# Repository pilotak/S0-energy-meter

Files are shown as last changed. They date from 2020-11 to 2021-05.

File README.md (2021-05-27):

# S0 energy meter
ESP8266 based pulse counter for home utility meter compatible with ESPHome, Tasmota, etc.

## Basic model
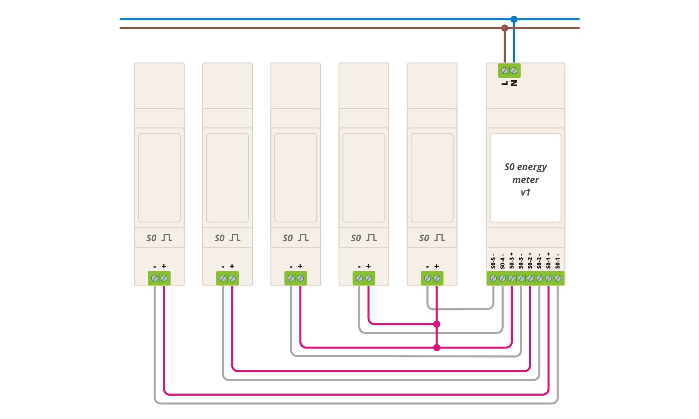
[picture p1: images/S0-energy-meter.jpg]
S0-energy-meter


**Features**:
- 230V direct power supply
- 5x S0 pulse meter input
- [ESPHome config](./config/S0-energy-meter.yaml)

## Enhanced model
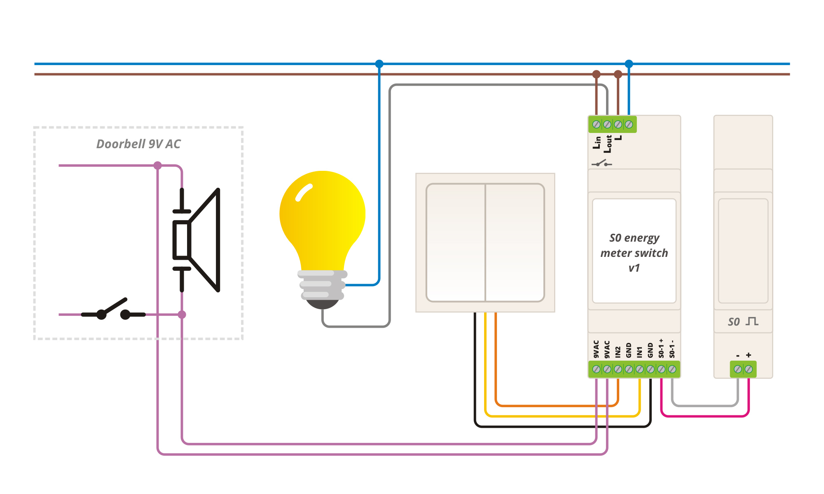
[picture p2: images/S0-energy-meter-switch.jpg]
S0-energy-meter-switch


**Features**:
- 230V direct power supply
- 1x S0 pulse meter input
- 2x input ie. for button or door sensor
- 1x SSR relay for light
- doorbell detection
- [ESPHome config](./config/S0-energy-meter-switch.yaml)

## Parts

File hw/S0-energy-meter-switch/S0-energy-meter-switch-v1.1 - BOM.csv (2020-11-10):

Qty | Value | Package | Description | Part
2 | 22uF/50V | PANASONIC_C | Aluminium Capacitor | C1, C5
1 | 10uF/6.3V | CT3528 | Tantalum Capacitor | C2
3 | 100n | C0805 | Ceramic Capacitor | C3, C4, C7
1 | 100n | C0805 | Ceramic Capacitor | C6
1 | 10uF/6.3V | C0805 | Ceramic Capacitor | C8
6 | KF350-3.5-2P | KF350-3.50-2P | Screw terminal 3.5mm pitch | CON1, CON2, CON3, CON4, CON5, CON6
1 | SS14 | DO214AC | Schottky Barrier Rectifier | D1
2 | UCLAMP3301D.TCT | SOD323 | Low Voltage μClamp TVS diode | D2, D5
1 | 1N4148WS | SOD323 | Fast Switching Diode | D3
1 | BAT54S | SOT23 | Schottky Diodes | D4
1 | TLP184 | SOP04 | AC Photocoupler | IC1
1 | 74LVC1G14GW.125 | SC70-5 | Single Schmitt-Trigger Inverter Gate | IC2
1 | MCP16301T-I/CH | SOT23-6 | High-Voltage Step-Down Regulator | IC3
1 | G3MB-202P-DC24 | G3MB | SSR Relay Zero Cross 2A, 100-240 VAC | K1
1 | DJNR3015-150 | L3015 | SMD Power Coil | L1
1 | RED | LED0805 | SMD LED Diode | LED1
2 | BC817-40SMD | SOT23-BEC | NPN Transistor | Q1, Q2
1 | 3K3 | R1206 | Resistor | R1
2 | 1K | R0805 | Resistor | R2, R13
10 | 10K | R0805 | Resistor | R3, R4, R5, R7, R10, R11, R12, R14, R15, R16
1 | 330R | R0805 | Resistor | R6
1 | 31K6 1% | R0805 | Resistor | R8
1 | 10K 1% | R0805 | Resistor | R9
1 | 820R | R0805 | Resistor | R17
1 | AC-DC_3.6W_24V_150mA | Module | AC-DC regulator | U1
1 | ESP8266-12 | ESP-12 | WIFI Module | U2

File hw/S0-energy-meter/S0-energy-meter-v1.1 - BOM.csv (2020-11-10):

Qty | Value | Package | Description | Part
2 | 22uF/50V | PANASONIC_C | Aluminium Capacitor | C1, C3
2 | 100n | C0805 | Ceramic Capacitor | C2, C5
1 | 100n | C0805 | Ceramic Capacitor | C4
1 | 10uF/6.3V | C0805 | Ceramic Capacitor | C6
4 | KF350-3.5-2P | KF350-3.50-2P | 2P Screw terminal 3.5mm pitch | CON1, CON2, CON3, CON4
1 | KF301-5.08-2P | KF301-5.08-2P | 2P Screw terminal 5.08mm pitch | CON5
1 | SS14 | DO214AC | Schottky Barrier Rectifier | D1
1 | 1N4148WS | SOD323 | Fast Switching Diode | D2
1 | BAT54S | SOT23 | Schottky Diodes | D3
1 | MCP16301T-I/CH | SOT23-6 | High-Voltage Step-Down Regulator | IC1
1 | DJNR3015-150 | L3015 | SMD Power Coil | L1
1 | RED | LED0805 | SMD LED Diode | LED1
5 | BC817-40SMD | SOT23-BEC | NPN Transistor | Q1, Q2, Q3, Q4, Q5
5 | 1K | R0805 | Resistor | R1, R4, R7, R12, R15
15 | 10K | R0805 | Resistor | R2, R3, R5, R6, R8, R9, R13, R14, R16, R17, R18, R19, R20, R21, R22
1 | 31K6 1% | R0805 | Resistor | R10
1 | 10K 1% | R0805 | Resistor | R11
1 | 820R | R0805 | Resistor | R23
1 | DTSM-3 | DTSM-3 | Push Button | S1
1 | AC-DC_3.6W_24V_150mA | Module | AC-DC regulator | U1
1 | ESP8266-12 | ESP-12 | WIFI Module | U2

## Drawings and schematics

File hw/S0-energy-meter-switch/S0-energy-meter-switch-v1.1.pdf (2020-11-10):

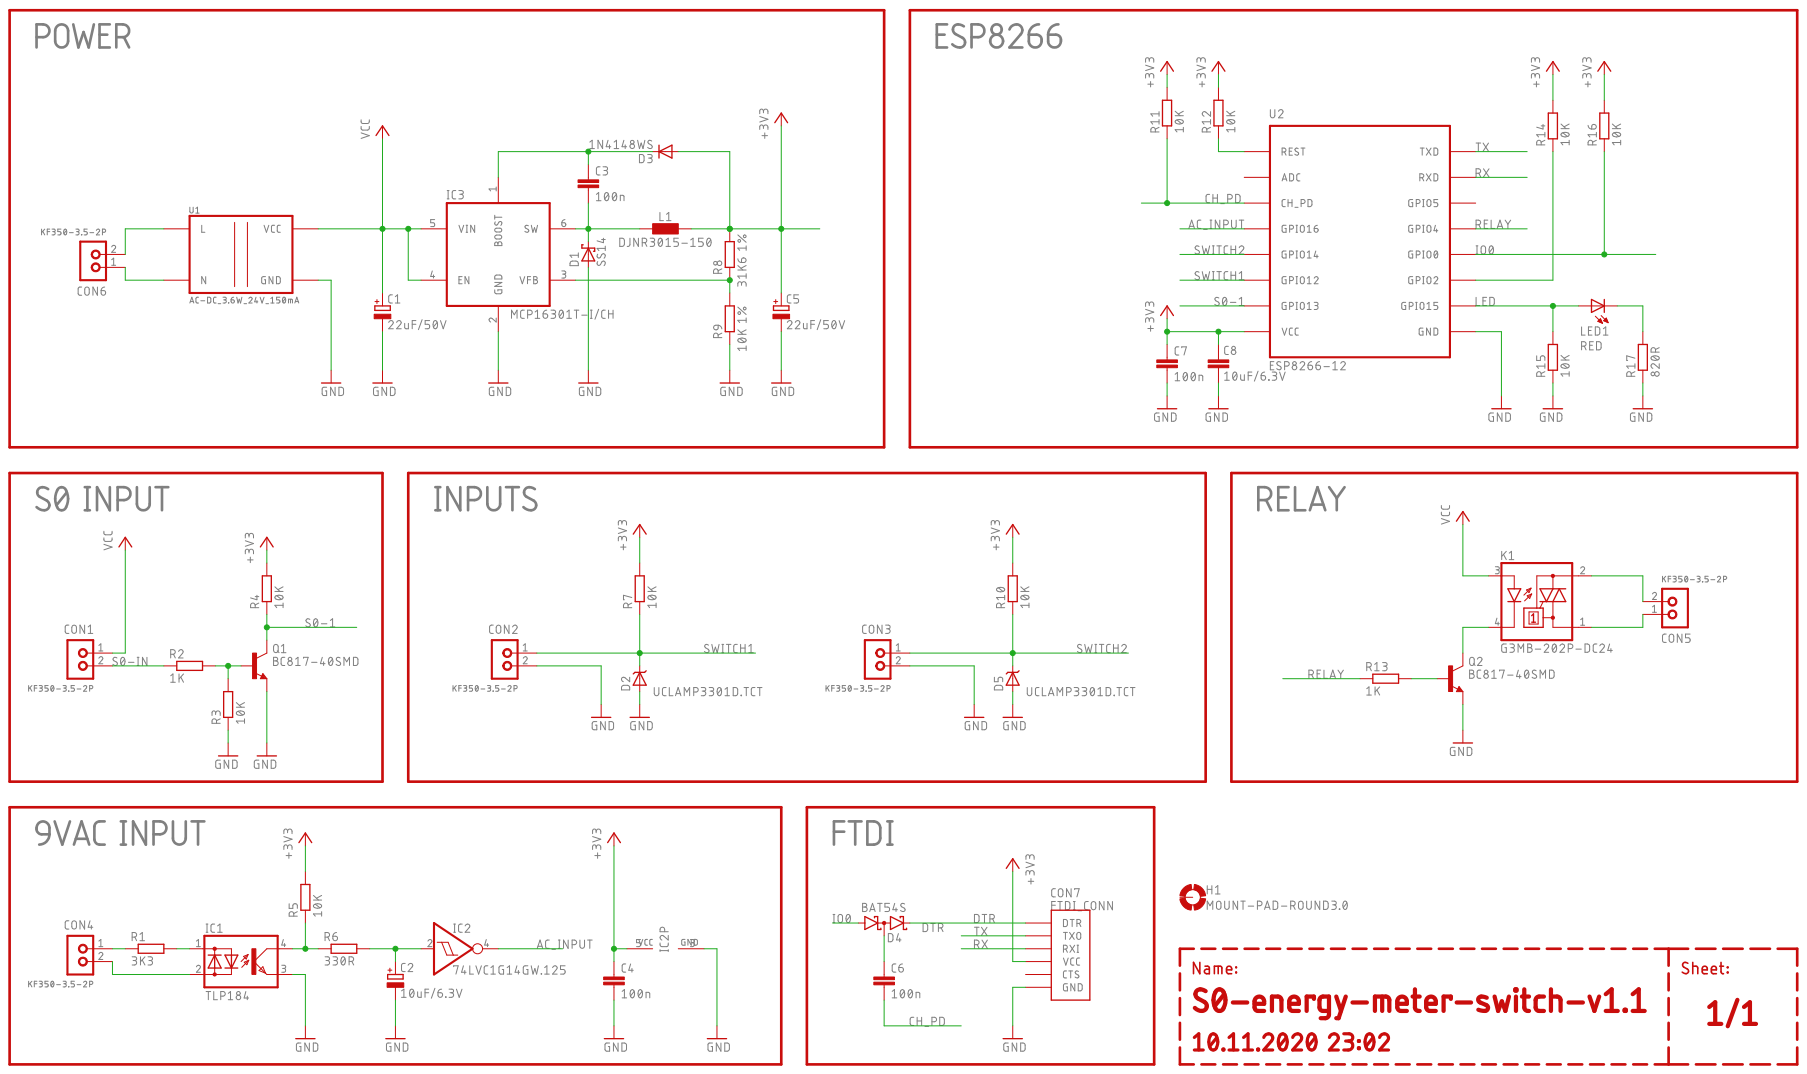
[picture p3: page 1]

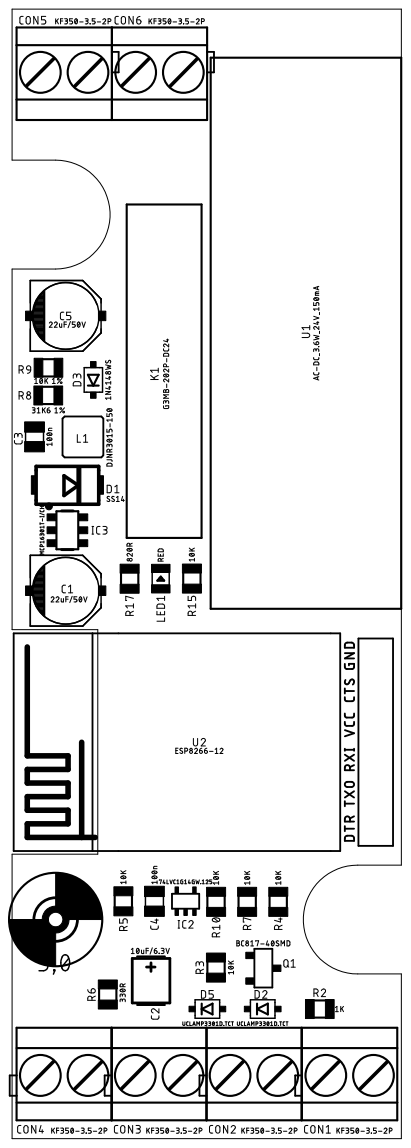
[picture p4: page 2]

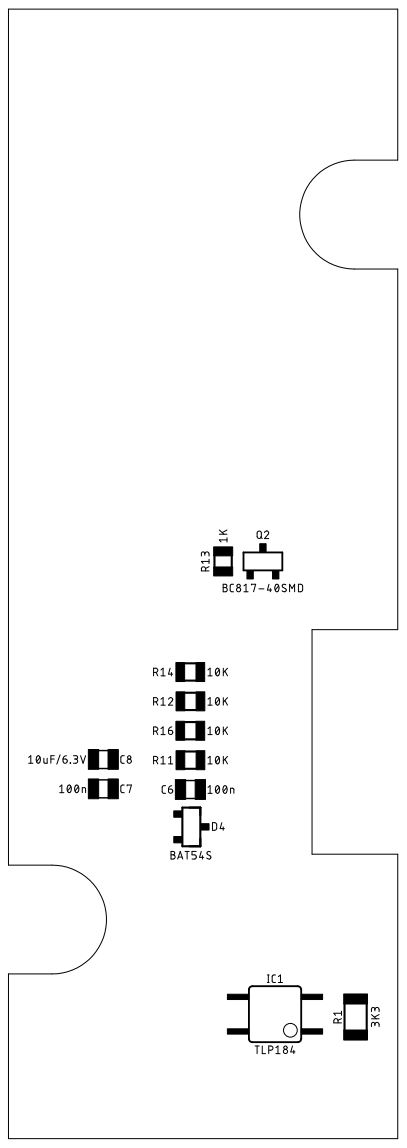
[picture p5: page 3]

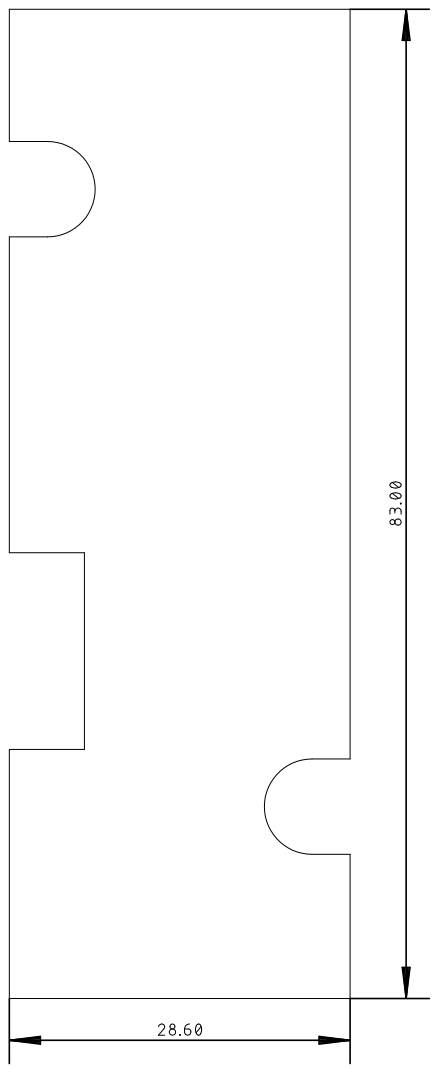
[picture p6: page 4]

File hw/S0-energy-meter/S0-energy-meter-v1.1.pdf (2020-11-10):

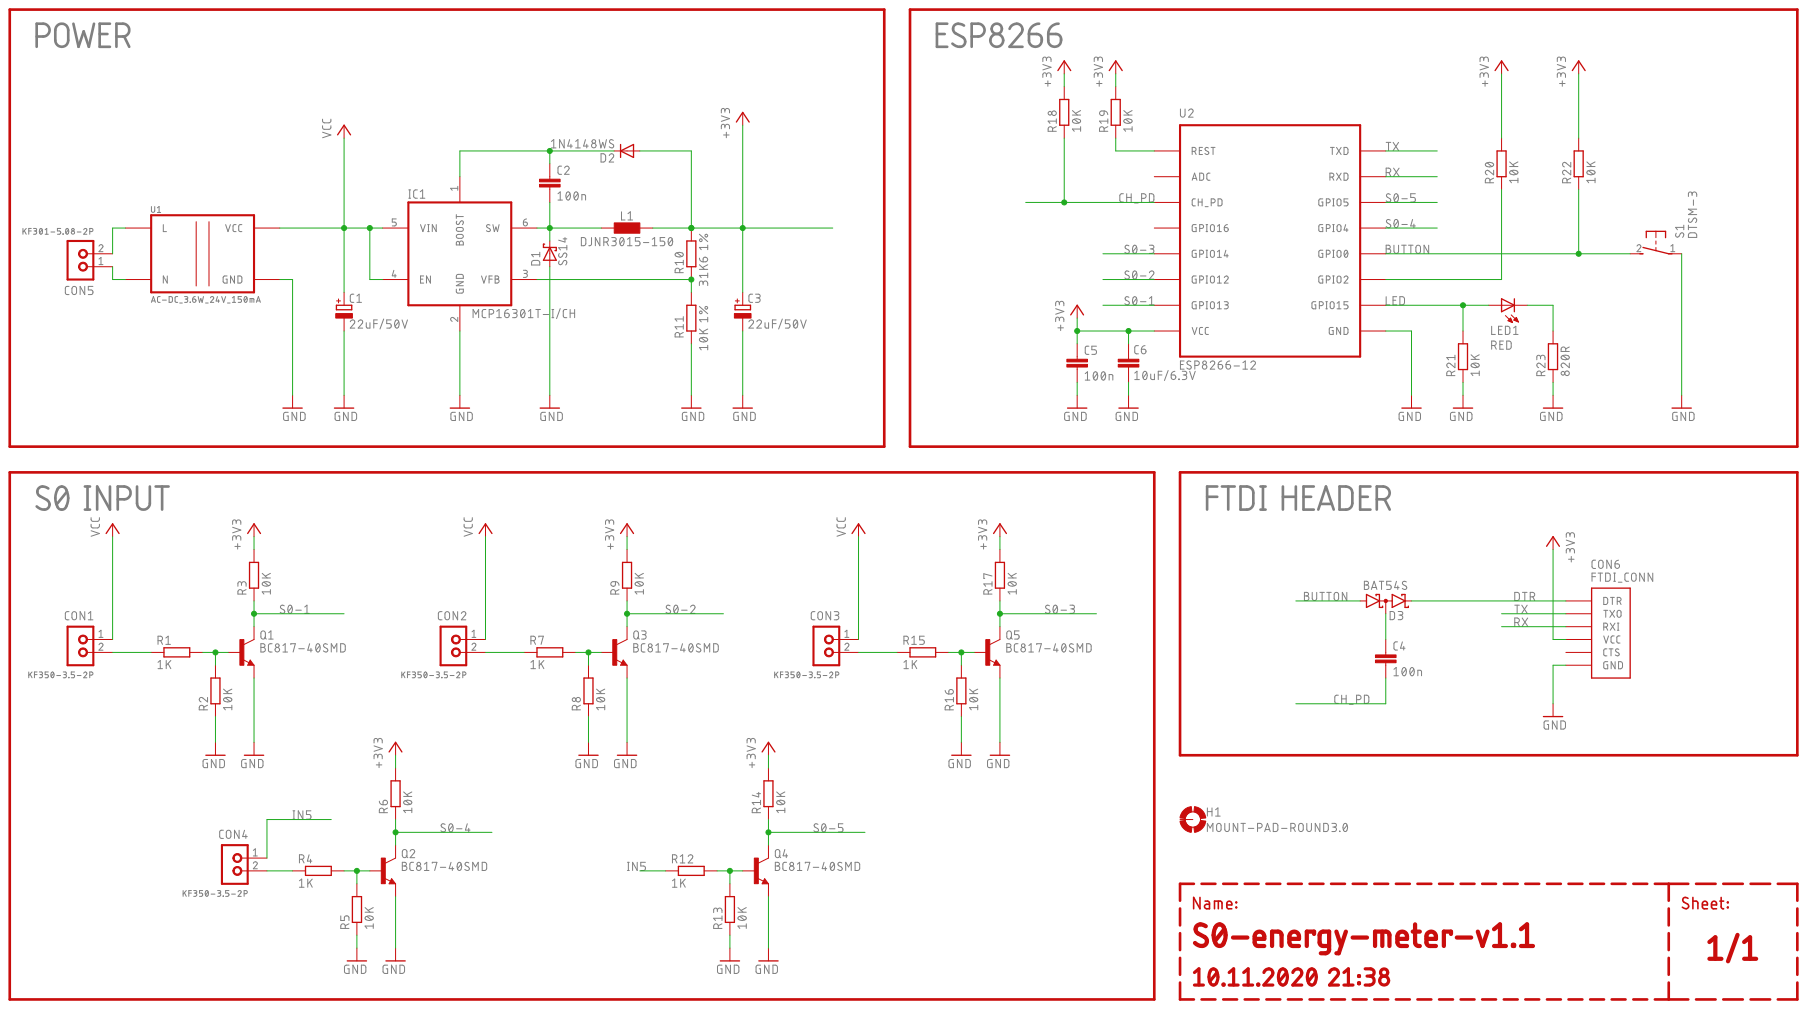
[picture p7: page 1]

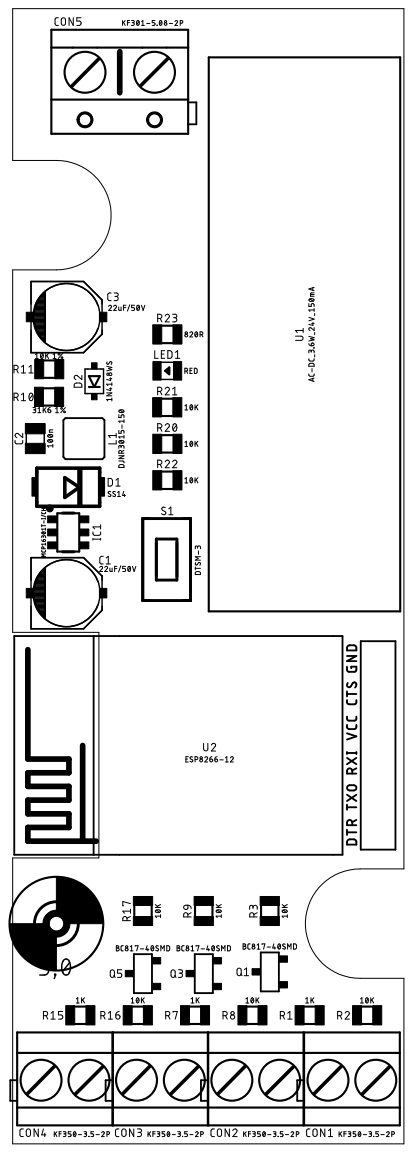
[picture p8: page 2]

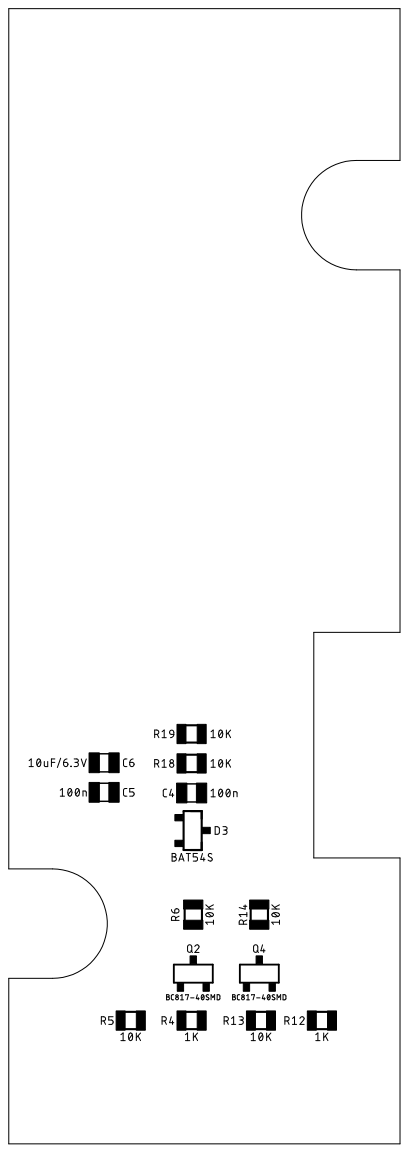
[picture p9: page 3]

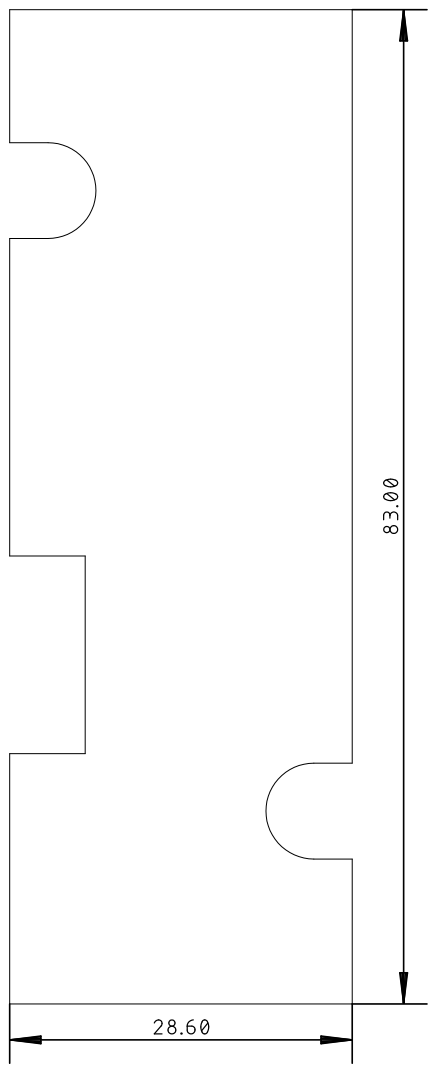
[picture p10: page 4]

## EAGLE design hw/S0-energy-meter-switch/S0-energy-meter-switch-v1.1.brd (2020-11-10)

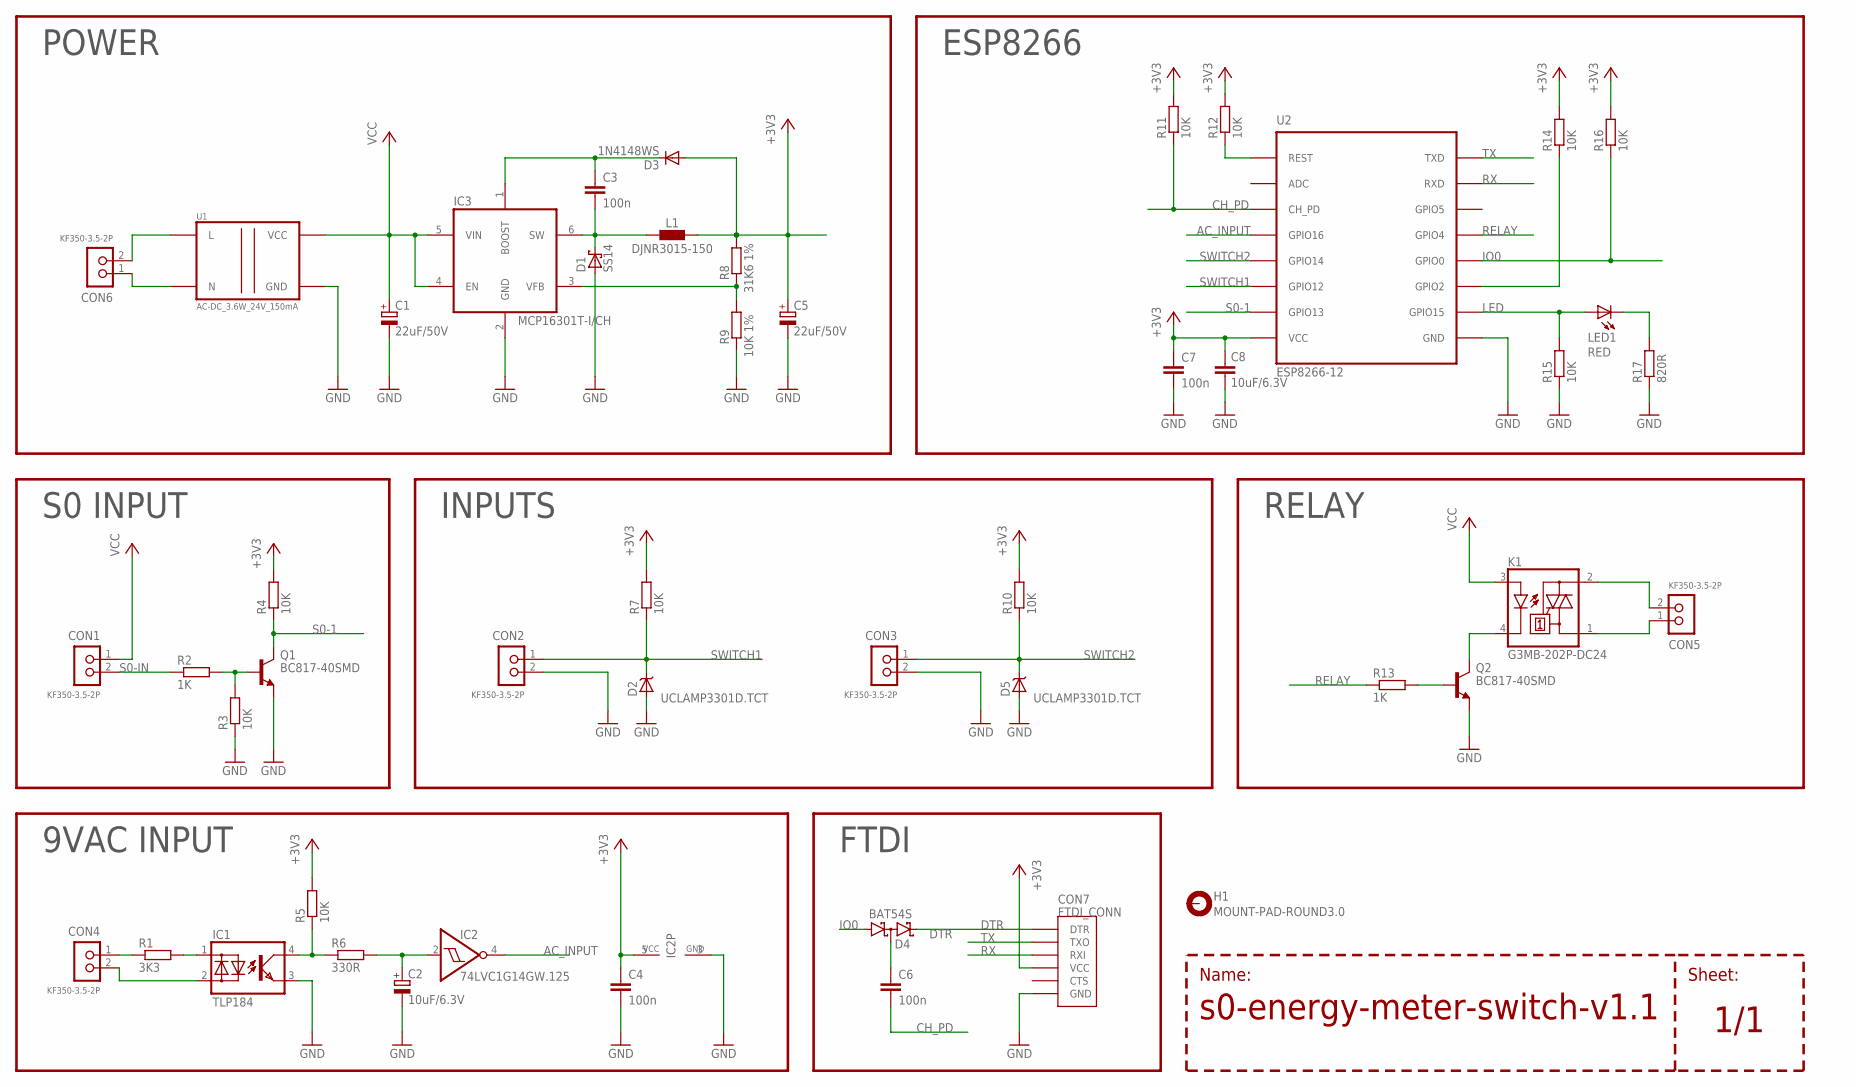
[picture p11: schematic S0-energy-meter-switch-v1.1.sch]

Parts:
C1, C5: 22uF/50V; PANASONIC_C
C2: 10uF/6.3V; CT3528
C3, C4, C6, C7: 100n; C0805
C8: 10uF/6.3V; C0805
CON1, CON2, CON3, CON4, CON5, CON6: KF350-3.5-2P; KF350-3.50-2P
CON7: FTDI_CONN; FTDI
D1: SS14; DO214AC
D2, D5: UCLAMP3301D.TCT; SOD323
D3: 1N4148WS; SOD323
D4: BAT54S; SOT23
H1: MOUNT-PAD-ROUND3.0; 3,0-PAD
IC1: TLP184; SOP04
IC2: 74LVC1G14GW.125; SC70-5
IC3: MCP16301T-I/CH; SOT23-6
K1: G3MB-202P-DC24; G3MB
L1: DJNR3015-150; L3015
LED1: RED; LED0805
Q1, Q2: BC817-40SMD; SOT23-BEC
R1: 3K3; R1206
R2, R13: 1K; R0805
R3, R4, R5, R7, R10, R11, R12, R14, R15, R16: 10K; R0805
R6: 330R; R0805
R8: 31K6 1%; R0805
R9: 10K 1%; R0805
R17: 820R; R0805
U1: AC-DC_3.6W_24V_150mA; AC_DC_24V_150MA
U2: ESP8266-12; ESP-12

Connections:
4: IC1.1 (A), R1.2
+3V3: C4.1, C5.+, C7.1, C8.1, CON7.P$4 (VCC), D3.A, IC2.5 (VCC), L1.1, R4.2, R5.2, R7.2, R8.2, R10.2, R11.2, R12.2, R14.2, R16.2, U2.VCC
AC_INPUT: IC2.4 (O), U2.GPIO16
CH: C6.1, D4.3 (C1A2)
CH_PD: C6.2, R11.1, U2.CH_PD
DTR: CON7.P$1 (DTR), D4.2 (C2)
GND: C1.-, C2.-, C4.2, C5.-, C7.2, C8.2, CON2.2, CON3.2, CON7.P$6 (GND), D1.A, D2.A, D5.A, IC1.3 (EMIT), IC2.3 (GND), IC3.2 (GND), Q1.E, Q2.E, R3.1, R9.1, R15.1, R17.1, U1.GND, U2.GND
IO0: D4.1 (A1), R16.1, U2.GPIO0
L: CON6.2, U1.L
LED: LED1.A, R15.2, U2.GPIO15
N: CON6.1, U1.N
unnamed: LED1.C, R17.2
unnamed: CON5.1, K1.1 (A1)
unnamed: Q1.B, R2.2, R3.2
unnamed: C2.+, IC2.2 (I), R6.2
unnamed: CON5.2, K1.2 (A2)
unnamed: CON4.2, IC1.2 (C)
unnamed: IC1.4 (COL), R5.1, R6.1
unnamed: K1.4 (C), Q2.C
unnamed: Q2.B, R13.2
unnamed: R12.1, U2.REST
unnamed: CON4.1, R1.1
unnamed: R14.1, U2.GPIO2
unnamed: C3.2, D1.C, IC3.6 (SW), L1.2
unnamed: C3.1, D3.C, IC3.1 (BOOST)
unnamed: IC3.3 (VFB), R8.1, R9.2
RELAY: R13.1, U2.GPIO4
RX: CON7.P$3 (RXI), U2.RXD
S0-1: Q1.C, R4.1, U2.GPIO13
S0-IN: CON1.2, R2.1
SWITCH1: CON2.1, D2.C, R7.1, U2.GPIO12
SWITCH2: CON3.1, D5.C, R10.1, U2.GPIO14
TX: CON7.P$2 (TXO), U2.TXD
VCC: C1.+, CON1.1, IC3.4 (EN), IC3.5 (VIN), K1.3 (A), U1.VCC

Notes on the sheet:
POWER
ESP8266
S0 INPUT
RELAY
9VAC INPUT
INPUTS
FTDI
Sheet:
Name:

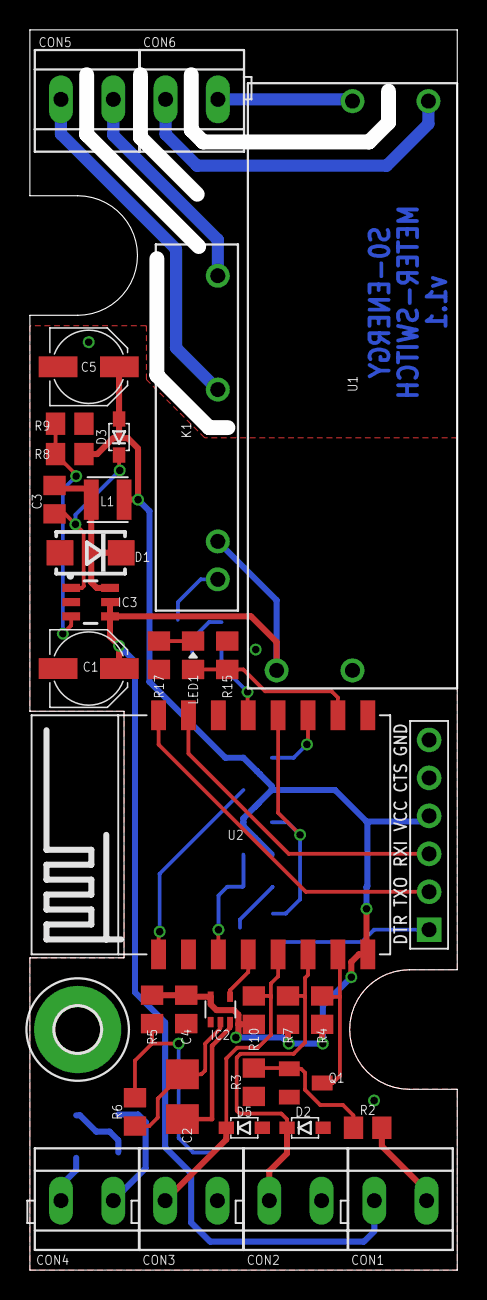
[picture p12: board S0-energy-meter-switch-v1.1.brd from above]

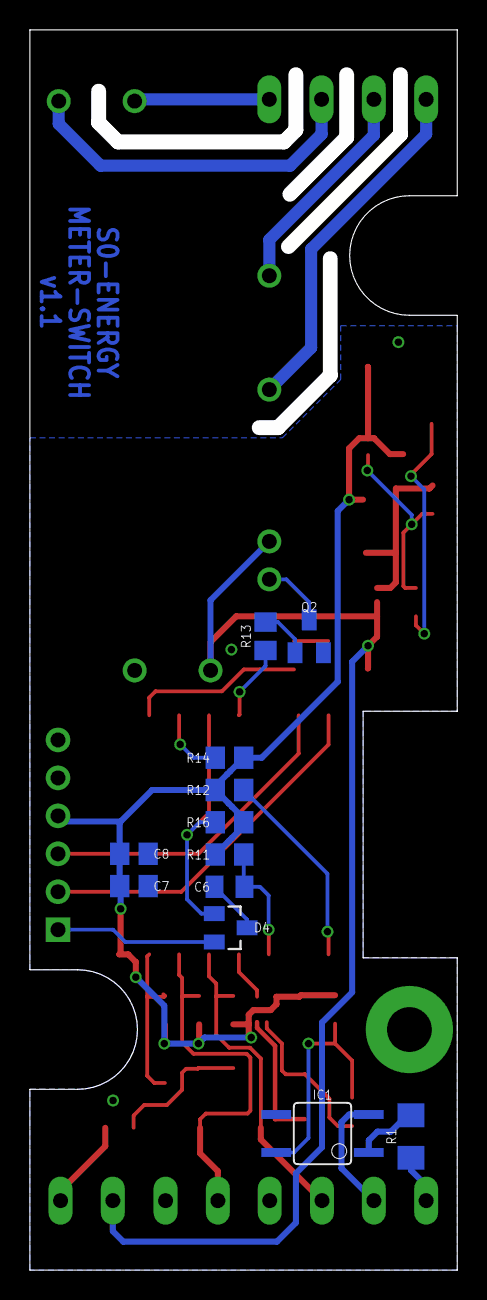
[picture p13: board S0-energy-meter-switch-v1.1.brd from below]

Board: 2 copper layers, 28.6 x 83.0 mm, 48 parts (12 on the bottom side), 34 nets.

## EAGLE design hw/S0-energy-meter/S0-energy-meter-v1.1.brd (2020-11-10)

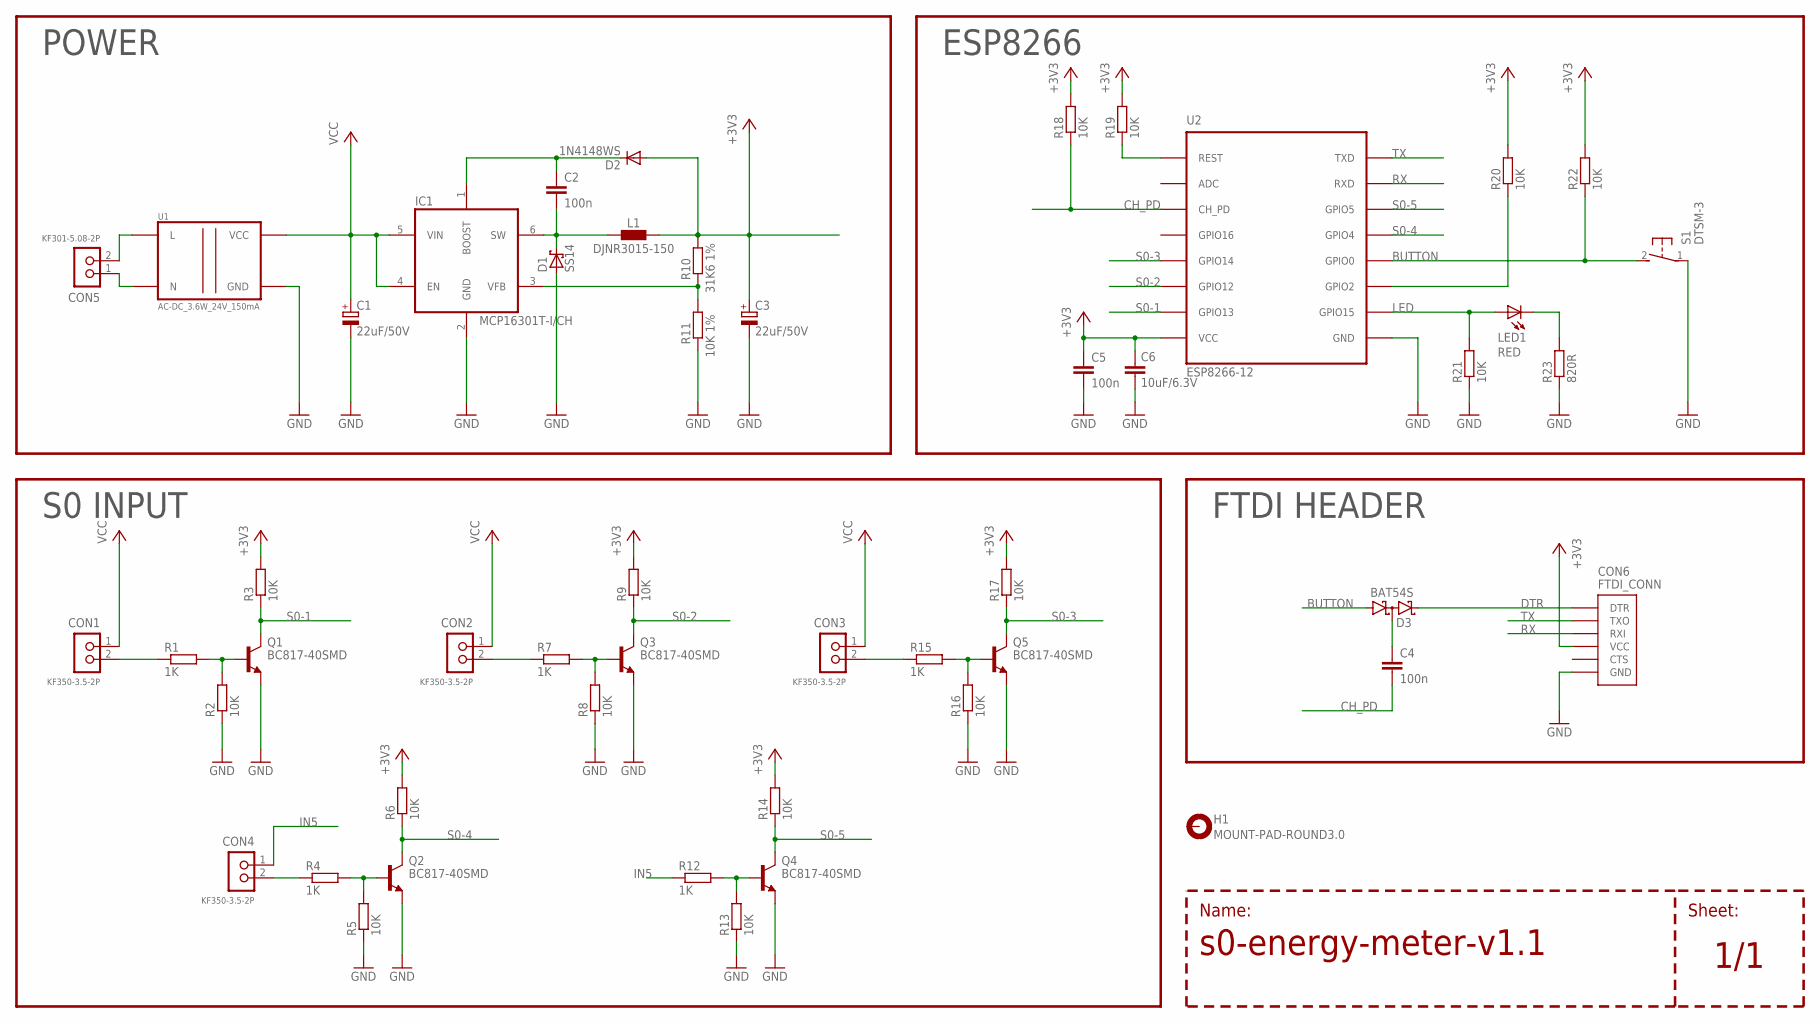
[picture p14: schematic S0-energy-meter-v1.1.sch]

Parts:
C1, C3: 22uF/50V; PANASONIC_C
C2, C4, C5: 100n; C0805
C6: 10uF/6.3V; C0805
CON1, CON2, CON3, CON4: KF350-3.5-2P; KF350-3.50-2P
CON5: KF301-5.08-2P
CON6: FTDI_CONN; FTDI
D1: SS14; DO214AC
D2: 1N4148WS; SOD323
D3: BAT54S; SOT23
H1: MOUNT-PAD-ROUND3.0; 3,0-PAD
IC1: MCP16301T-I/CH; SOT23-6
L1: DJNR3015-150; L3015
LED1: RED; LED0805
Q1, Q2, Q3, Q4, Q5: BC817-40SMD; SOT23-BEC
R1, R4, R7, R12, R15: 1K; R0805
R2, R3, R5, R6, R8, R9, R13, R14, R16, R17, R18, R19, R20, R21, R22: 10K; R0805
R10: 31K6 1%; R0805
R11: 10K 1%; R0805
R23: 820R; R0805
S1: DTSM-3
U1: AC-DC_3.6W_24V_150mA; AC_DC_24V_150MA
U2: ESP8266-12; ESP-12

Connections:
+3V3: C3.+, C5.1, C6.1, CON6.P$4 (VCC), D2.A, L1.1, R3.2, R6.2, R9.2, R10.2, R14.2, R17.2, R18.2, R19.2, R20.2, R22.2, U2.VCC
BUTTON: D3.1 (A1), R22.1, S1.2, U2.GPIO0
CH: C4.1, D3.3 (C1A2)
CH_PD: C4.2, R18.1, U2.CH_PD
DTR: CON6.P$1 (DTR), D3.2 (C2)
GND: C1.-, C3.-, C5.2, C6.2, CON6.P$6 (GND), D1.A, IC1.2 (GND), Q1.E, Q2.E, Q3.E, Q4.E, Q5.E, R2.1, R5.1, R8.1, R11.1, R13.1, R16.1, R21.1, R23.1, S1.1, U1.GND, U2.GND
IN1: CON1.2, R1.1
IN2: CON2.2, R7.1
IN3: CON3.2, R15.1
IN4: CON4.2, R4.1
IN5: CON4.1, R12.1
LED: LED1.A, R21.2, U2.GPIO15
unnamed: LED1.C, R23.2
unnamed: Q1.B, R1.2, R2.2
unnamed: Q3.B, R7.2, R8.2
unnamed: Q5.B, R15.2, R16.2
unnamed: Q2.B, R4.2, R5.2
unnamed: R19.1, U2.REST
unnamed: CON5.2, U1.L
unnamed: CON5.1, U1.N
unnamed: Q4.B, R12.2, R13.2
unnamed: C2.2, D1.C, IC1.6 (SW), L1.2
unnamed: C2.1, D2.C, IC1.1 (BOOST)
unnamed: IC1.3 (VFB), R10.1, R11.2
unnamed: R20.1, U2.GPIO2
RX: CON6.P$3 (RXI), U2.RXD
S0-1: Q1.C, R3.1, U2.GPIO13
S0-2: Q3.C, R9.1, U2.GPIO12
S0-3: Q5.C, R17.1, U2.GPIO14
S0-4: Q2.C, R6.1, U2.GPIO4
S0-5: Q4.C, R14.1, U2.GPIO5
TX: CON6.P$2 (TXO), U2.TXD
VCC: C1.+, CON1.1, CON2.1, CON3.1, IC1.4 (EN), IC1.5 (VIN), U1.VCC

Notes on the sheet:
POWER
ESP8266
S0 INPUT
FTDI HEADER
Sheet:
Name:

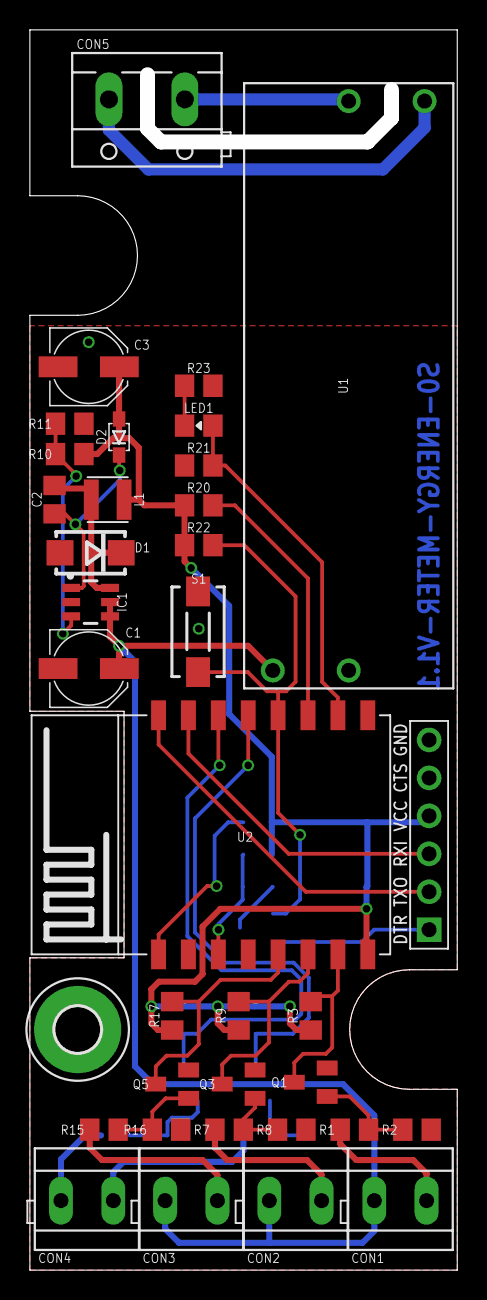
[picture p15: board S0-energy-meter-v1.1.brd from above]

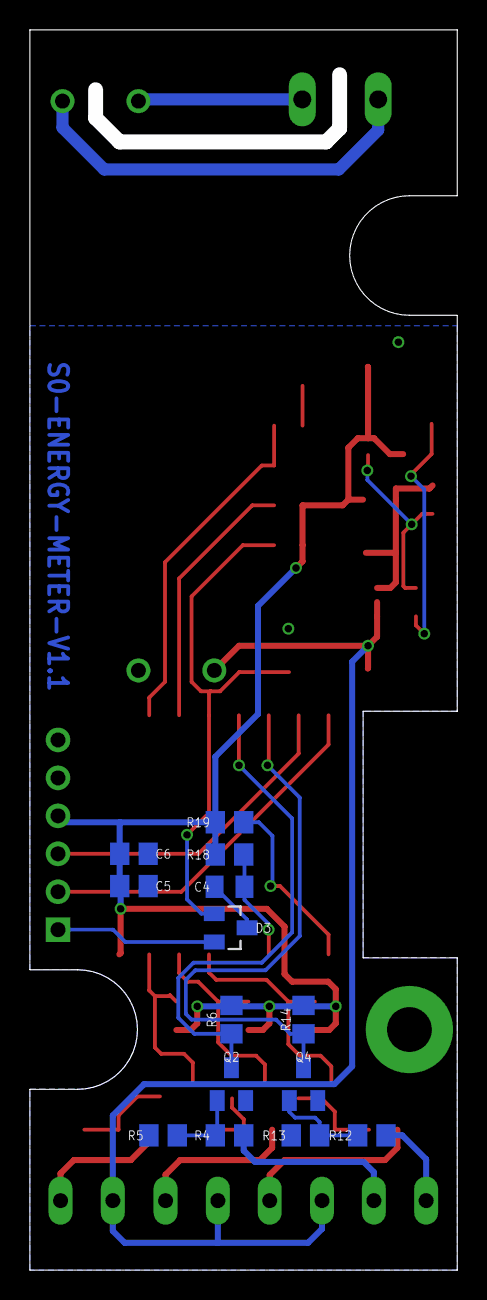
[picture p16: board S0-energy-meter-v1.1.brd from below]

Board: 2 copper layers, 28.6 x 83.0 mm, 50 parts (14 on the bottom side), 33 nets.

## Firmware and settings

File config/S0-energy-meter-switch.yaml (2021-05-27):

esphome:
  name: "Energy meter swtich"
  platform: ESP8266
  board: esp01_1m
  esp8266_restore_from_flash: True

wifi:
  fast_connect: true
  networks:
  - ssid: !secret ssid
    password: !secret password

logger:

# Enable Home Assistant API
api:

ota:

sensor:
  - platform: pulse_counter
    pin: GPIO13
    name: "Power consumption 1"
    id: power1
    unit_of_measurement: 'Wh'
    internal_filter: 10ms
    filters:
      - multiply: 16.66666666666
    count_mode:
      rising_edge: DISABLE
      falling_edge: INCREMENT

  - platform: total_daily_energy
    name: "Daily power consumption 1"
    icon: "mdi:current-ac"
    power_id: power1
    unit_of_measurement: 'kWh'
    filters:
      - multiply: 0.001

output:
  - platform: gpio
    pin: GPIO4
    id: relay

light:
  - platform: binary
    name: "Light 1"
    id: light1
    output: relay

binary_sensor:
  - platform: status
    name: "Energy meter switch: status"

  - platform: gpio
    name: "Doorbell"
    pin:
      number: GPIO16
      inverted: False

  - platform: gpio
    name: "Door sensor"
    device_class: door
    pin:
      number: GPIO14
      inverted: True

  - platform: gpio
    name: "Switch 1"
    on_press:
      then:
        - light.turn_on: light1
    on_release:
      then:
        - light.turn_off: light1
    pin:
      number: GPIO12
      inverted: True

time:
  - platform: homeassistant
    id: homeassistant_time
    timezone: "Europe/Prague"
    
status_led:
  pin:
    number: GPIO15

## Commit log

2020-11-10 folder restructure
    [S0-energy-meter-v1.1 - BOM.csv, S0-energy-meter-v1.1.brd, S0-energy-meter-v1.1.sch]
2020-11-10 add meter with switch
    [S0-energy-meter-switch-v1.1 - BOM.csv, S0-energy-meter-switch-v1.1.brd, S0-energy-meter-switch-v1.1.sch]
